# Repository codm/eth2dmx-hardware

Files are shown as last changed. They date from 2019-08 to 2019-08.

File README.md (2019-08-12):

# Ethernet DMX Bridge

The Ethernet DMX Bridge is an open-source hardware solution to generate DMX signals mainly for lightning applications.

It is based on the work from the [LoxForum](https://www.loxforum.com/forum/faqs-tutorials-howto-s/34948-g%C3%BCnstige-und-bessere-alternative-zur-dmx-extension), a german Loxone community. The Software ist mainly developed by Robert Lechner: https://sourceforge.net/p/udptodmx/code/HEAD/tree/trunk/ with extensions from us (cod.m GmbH).
The development of this software has moved to github: https://github.com/LechnerRobert/UDPtoDMX/

The hardware was developed to be a finished product (including CE and RoHS) which can be mounted in a DIN-Rail enclosure - an electric cabinet - so that electricians and alike have not to build their own using some dodgy hardware and perfboards.

To buy one, visit https://shop.codm.de/module/8/ethernet-dmx-bridge-v0.4

## Hardware

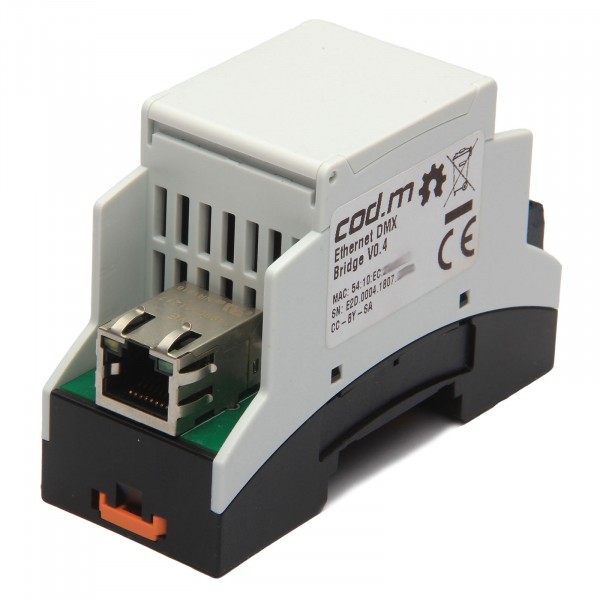
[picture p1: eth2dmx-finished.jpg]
Ethernet DMX Bridge, finished with casing


We've built it with a wide input voltage range (7-36V), protection for the RS485/DMX-Bus and an easy to use DHCP option with an unique EUID48. Also we've added a short circuit protection.

The second big thing was power consumption. We are currently using not more tha 0.34W for the complete unit. Achieved is this by using WizNets W5500 instead of the (older) W5100 and by using the original MAX485 from Maxim.

You can read about the built in Patrik Mayer's blog: https://allgeek.de/2018/07/22/professionelle-ethernet-dmx-bridge-udp/ (german)

## Software

We've used mainly the original software from Robert but extended it for the EUDI48 use and maintaining the DHCP IP address. 

For the network part we rely on Paull Stoffregens marvelous ethernet library, which is meanwhile the one shipped with the arduino IDE by default.
As this library currently does not have a way to set the ethernet hostname, we've [forked](https://github.com/codm/Ethernet) the library and added it. 

Please follow Robert's instructions on compiling and use our version of the libraries when enabling certain features.

## Legal

We do __not__ allow reproduction of the hardware without our consent. If you wan't to use the schematics and/or board in your own private project, feel free. But don't use __any__ of this in a commercial manner without contacting us!

(c) cod.m GmbH, 2018, Germany - CC-BY-SA

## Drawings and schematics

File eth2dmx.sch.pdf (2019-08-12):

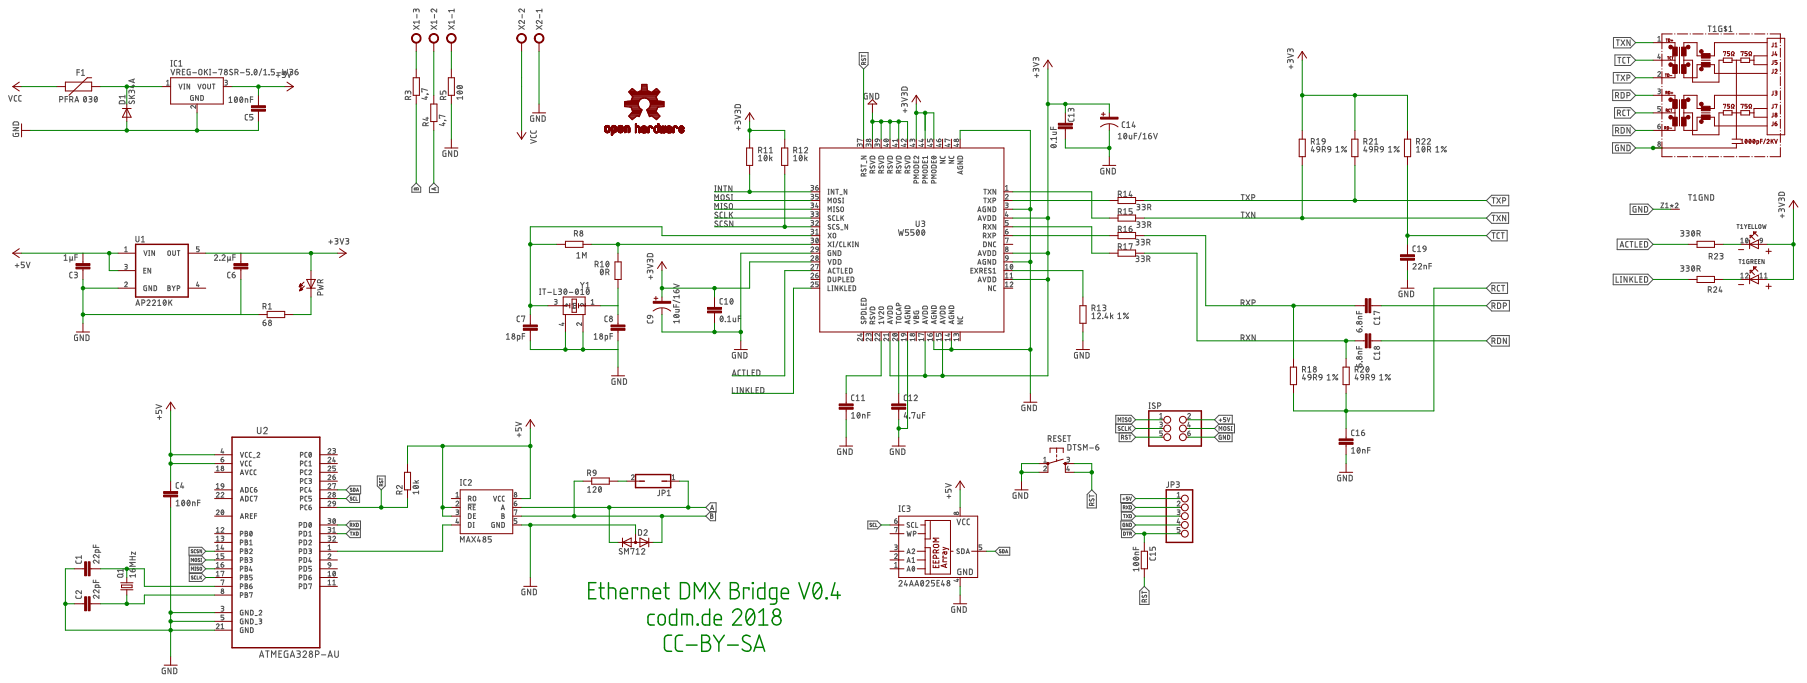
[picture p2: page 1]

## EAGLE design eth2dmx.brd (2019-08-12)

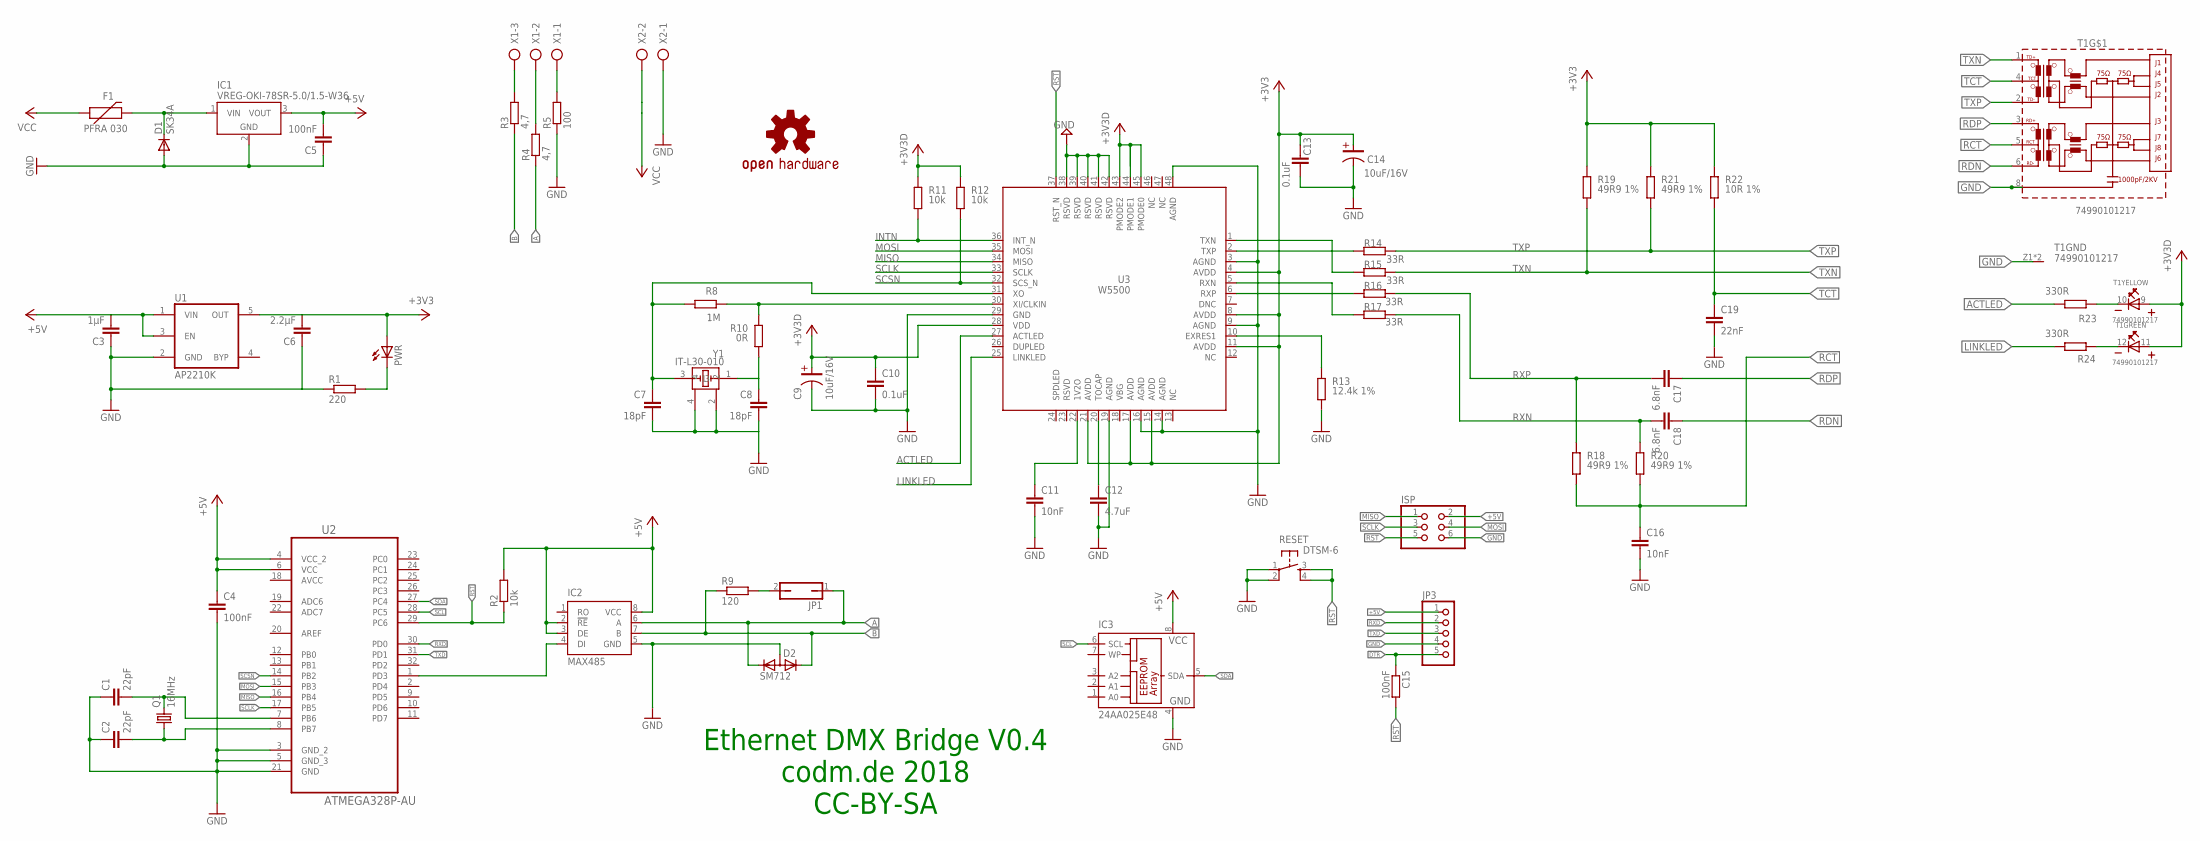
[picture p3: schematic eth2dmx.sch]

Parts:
C1, C2: 22pF; C0805
C3: 1µF; C0805
C4, C5: 100nF; C0805
C6: 2.2µF; C0805
C7, C8: 18pF; C0805
C9, C14: 10uF/16V; C-3216(TANTAL)
C10, C13: 0.1uF; C0805
C11, C16: 10nF; C0805
C12: 4.7uF; C0805
C15: 100nF; R0805
C17, C18: 6.8nF; C0805
C19: 22nF; C0805
D1: SK34A; DO214AC
D2: SM712; SOT23
F1: PFRA 030; PTH
IC1: VREG-OKI-78SR-5.0/1.5-W36; OKI-78SR
IC2: MAX485; SOIC8
IC3: 24AA025E48; SO-08
ISP: PINHD-2X3; 2X03
JP1: JP1Q; JP1
JP3: PINHD-1X5; 1X05
LOGO1: OSHW-LOGOM; OSHW-LOGO-M
PWR: LEDCHIP-LED0805; CHIP-LED0805
Q1: 16MHz; HC49U70
R1: 220; R0805
R2, R11, R12: 10k; R0805
R3, R4: 4,7; R0805
R5: 100; R0805
R8: 1M; R0805
R9: 120; R0805
R10: 0R; R0805
R13: 12.4k 1%; R0805
R14, R15, R16, R17: 33R; R0805
R18, R19, R20, R21: 49R9 1%; R0805
R22: 10R 1%; R0805
R23, R24: 330R; R0805
RESET: DTSM-6
T1: 74990101217; 74990111217
U1: AP2210K; SOT23-5
U2: ATMEGA328P-AU; QFP80P900X900X120-32N
U3: W5500
X1: AK500/3
X2: AK500/2
Y1: IT-L30-010

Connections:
+3V3: C6.2, C9.1, C10.1, C13.1, C14.1, PWR.A, R11.2, R12.2, R19.2, R21.2, R22.2, T1.9 (A), T1.11 (A), U1.5 (OUT), U3.4 (AVDD), U3.8 (AVDD), U3.11 (AVDD), U3.15 (AVDD), U3.17 (AVDD), U3.21 (AVDD), U3.28 (VDD), U3.43 (PMODE2), U3.44 (PMODE1), U3.45 (PMODE0)
+5V: C3.2, C4.1, C5.2, IC1.3 (VOUT), IC2.2 (!RE), IC2.3 (DE), IC2.8 (VCC), IC3.8 (VCC), ISP.2, JP3.1, R2.2, U1.1 (VIN), U1.3 (EN), U2.4 (VCC_2), U2.6 (VCC)
A: D2.1 (K1), IC2.6 (A), JP1.1, R4.1
ACTLED: R23.1, U3.27 (ACTLED)
AVCC: U2.18 (AVCC)
B: D2.2 (K2), IC2.7 (B), R3.1, R9.1
DOUT: IC2.4 (DI), U2.1 (PD3)
DTR: C15.1, JP3.5
GND: C1.1, C2.1, C3.1, C4.2, C5.1, C6.1, C7.2, C8.2, C9.2, C10.2, C11.2, C12.2, C13.2, C14.2, C16.2, C19.2, D1.A, D2.3 (A), IC1.2 (GND), IC2.5 (GND), IC3.4 (GND), ISP.6, JP3.4, R1.1, R5.1, R13.1, RESET.1, RESET.2, T1.8, T1.Z1 (GND), T1.Z2 (GND), U1.2 (GND), U2.3 (GND_2), U2.5 (GND_3), U2.21 (GND), U3.3 (AGND), U3.9 (AGND), U3.14 (AGND), U3.16 (AGND), U3.19 (AGND), U3.29 (GND), U3.38 (RSVD), U3.39 (RSVD), U3.40 (RSVD), U3.41 (RSVD), U3.42 (RSVD), U3.48 (AGND), X2.1, Y1.2, Y1.4
INTN: R11.1, U3.36 (INT_N)
LINKLED: R24.1, U3.25 (LINKLED)
MISO: ISP.1, U2.16 (PB4), U3.34 (MISO)
MOSI: ISP.4, U2.15 (PB3), U3.35 (MOSI)
unnamed: C12.1, U3.20 (TOCAP)
unnamed: C2.2, Q1.1, U2.8 (PB7)
unnamed: C1.2, Q1.2, U2.7 (PB6)
unnamed: R5.2, X1.1
unnamed: R3.2, X1.3
unnamed: R4.2, X1.2
unnamed: PWR.C, R1.2
unnamed: D1.C, F1.P$2 (2), IC1.1 (VIN)
unnamed: R8.2, R10.2, U3.30 (XI/CLKIN)
unnamed: JP1.2, R9.2
unnamed: C11.1, U3.22 (1V2O)
unnamed: R13.2, U3.10 (EXRES1)
unnamed: R16.2, U3.6 (RXP)
unnamed: C7.1, R8.1, U3.31 (XO), Y1.3
unnamed: R17.2, U3.5 (RXN)
unnamed: R14.2, U3.2 (TXP)
unnamed: R15.2, U3.1 (TXN)
unnamed: C8.1, R10.1, Y1.1
unnamed: R23.2, T1.10 (K)
unnamed: R24.2, T1.12 (K)
RCT: C16.1, R18.1, R20.1, T1.5 (RCT)
RDN: C18.1, T1.6 (RD-)
RDP: C17.1, T1.3 (RD+)
RST: C15.2, ISP.5, R2.1, RESET.3, RESET.4, U2.29 (PC6), U3.37 (RST_N)
RXD: JP3.2, U2.30 (PD0)
RXN: C18.2, R17.1, R20.2
RXP: C17.2, R16.1, R18.2
SCL: IC3.6 (SCL), U2.28 (PC5)
SCLK: ISP.3, U2.17 (PB5), U3.33 (SCLK)
SCSN: R12.1, U2.14 (PB2), U3.32 (SCS_N)
SDA: IC3.5 (SDA), U2.27 (PC4)
TCT: C19.1, R22.1, T1.4 (TCT)
TXD: JP3.3, U2.31 (PD1)
TXN: R15.1, R19.1, T1.1 (TD+)
TXP: R14.1, R21.1, T1.2 (TD-)
VCC: F1.P$1 (1), X2.2

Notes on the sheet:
Ethernet DMX Bridge V0.4 codm.de 2018 CC-BY-SA

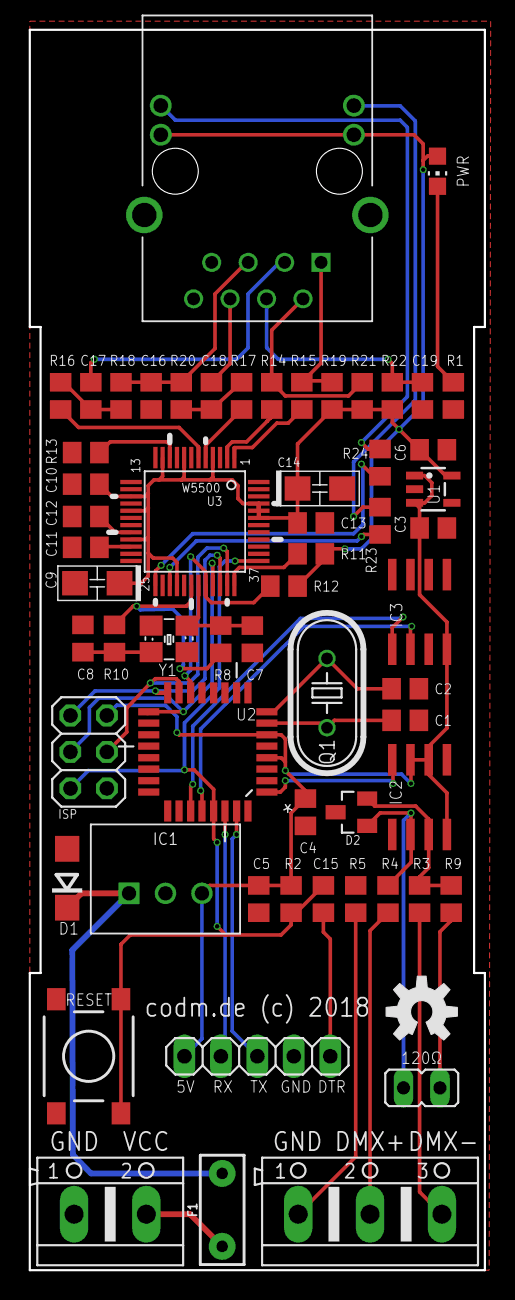
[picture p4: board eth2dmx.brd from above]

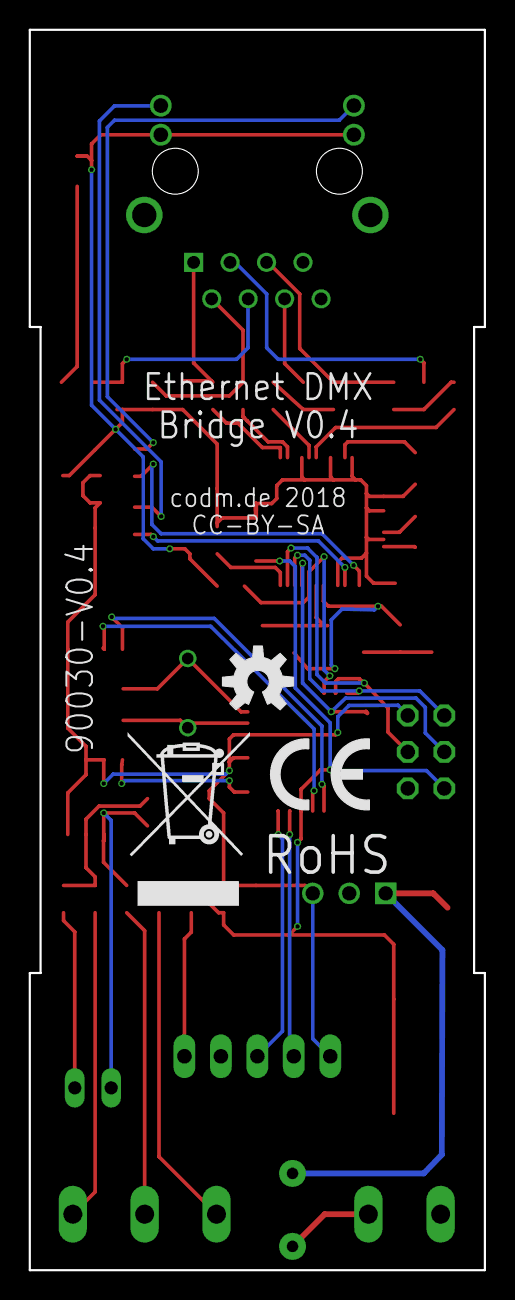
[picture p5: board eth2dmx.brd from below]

Board: 2 copper layers, 31.7 x 86.4 mm, 64 parts (3 on the bottom side), 48 nets.

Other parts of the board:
LOGO2: OSHW-LOGOM; OSHW-LOGO-M
U$1: CE_5MM
U$3: WEEE-LOGO-8MM

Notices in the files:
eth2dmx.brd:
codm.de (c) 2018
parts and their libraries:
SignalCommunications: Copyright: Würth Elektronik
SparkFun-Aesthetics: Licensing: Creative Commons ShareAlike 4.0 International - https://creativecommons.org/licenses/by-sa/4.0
